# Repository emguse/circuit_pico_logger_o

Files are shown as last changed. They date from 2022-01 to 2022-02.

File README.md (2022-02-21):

# pico_logger_o

A device to record the rate of change of differential pressure using an OMRON D6F sensor, built with Raspberry Pi pico and CircuitPython.

A personal project of `emguse`, a port of the [emguse/diff_press_logger_o](https://github.com/emguse/diff_press_logger_o) project to a microcontroller.

# Notes.
- The PB-0009-A PCB board has three different power input methods, but there is no diode protection between each of them.
- Always use only one type of power input.
- If you are using the Pico's USB to supply power, it will not be able to provide power for the printer. Do not connect the printer or turn off the setting to use it.

# Features
- Time recording by RTC
- Event recording (CSV file)
- Event recording (print to thermal printer)
- Pre- and post-event recording is possible. (Number of seconds can be set.)
- Trigger detection using differences from past measurements
- Threshold change button
- Reset button

# What you need

## What to buy
- Rapberry Pi pico RP2040
- OMRON D6F-PH0505 Differential pressure sensor
- special harness with GHR-04V-S used for D6F-PH0505
- Adafruit DS3231 Precision RTC-STEMMA QT(Product ID: 5188)
- STEMMA QT / Qwiic JST SH 4-pin Cable - 100mm Long(Product ID: 4210)
- Adafruit Micro SD SPI or SDIO Card Breakout Board(Product ID: 4682)
- Thermal printer DP-EH600
- 5V 2A power supply (2.1mm DC barrel plug)

## Printed circuit board
- PB-0009-A PCB board
- 2.1mm DC barrel jack
- B2B-XH-AM(LF)(SN) JST
- B3B-XH-AM(LF)(SN) JST
- B8B-XH-AM(LF)(SN) JST
- 2.2k Ohm Resistor_SMD:R_0603_1608Metric
- 3.3k Ohm Resistor_SMD:R_0603_1608Metric
- 10k Ohm Resistor_SMD:R_0603_1608Metric
- PinHeader_1x02_P2.54mm_Vertical
- SW_Push_1P1T_NO_6x6mm
- Buzzer_12x9.5RM7.6(self-excited)
- 2SC2712 Toshiba
- BM04B-SRSS-TB_1x04-1MP_P1.00mm_Vertical JST SH

## airtight container
- enclosure_body.stl
- enclosure_lid.stl
- enclosure_sensor_fixture.stl
- Bit Insert M3x4.5xL10.0
- M3x16mm cap screws
- O-ring d84.4mm-D90.6mm-W3.1mm(G-85)
- Cable gland M10x13mm d6mm (ex. RM10L-6B takachi)
- 6mmx4mm Tube

# Usage

1. Connect Pico to your PC in Boot mode and transfer the latest `.UF2` file for Pico.
1. Transfer the modules listed in `Requirement` from the Circuitpython bundle to the `lib` folder.
1. Rename the `pico_diff_p_o.py` file to `code.py` after transferring the files in this repository.

# Requirement
- adafruit_bus_device.i2c_device
- adafruit_register
- adafruit_thermal_printer
- adafruit_ds3231

# Author

- Author: emguse

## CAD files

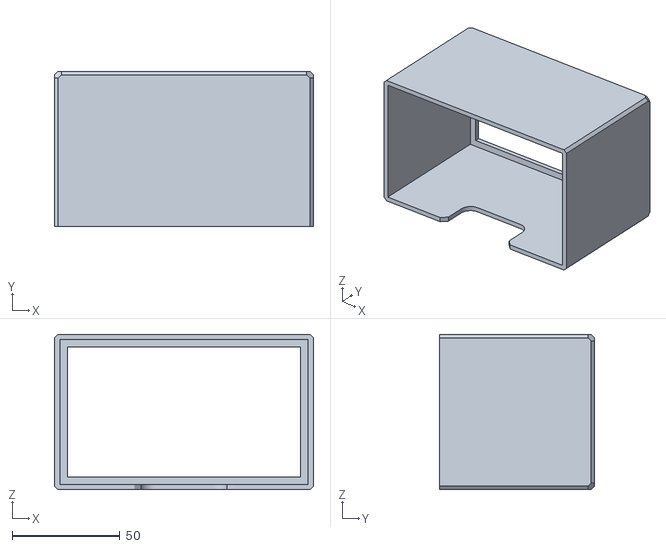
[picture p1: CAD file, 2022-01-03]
DP-EH600_Housing v1.stl
120.0 x 72.0 x 72.0

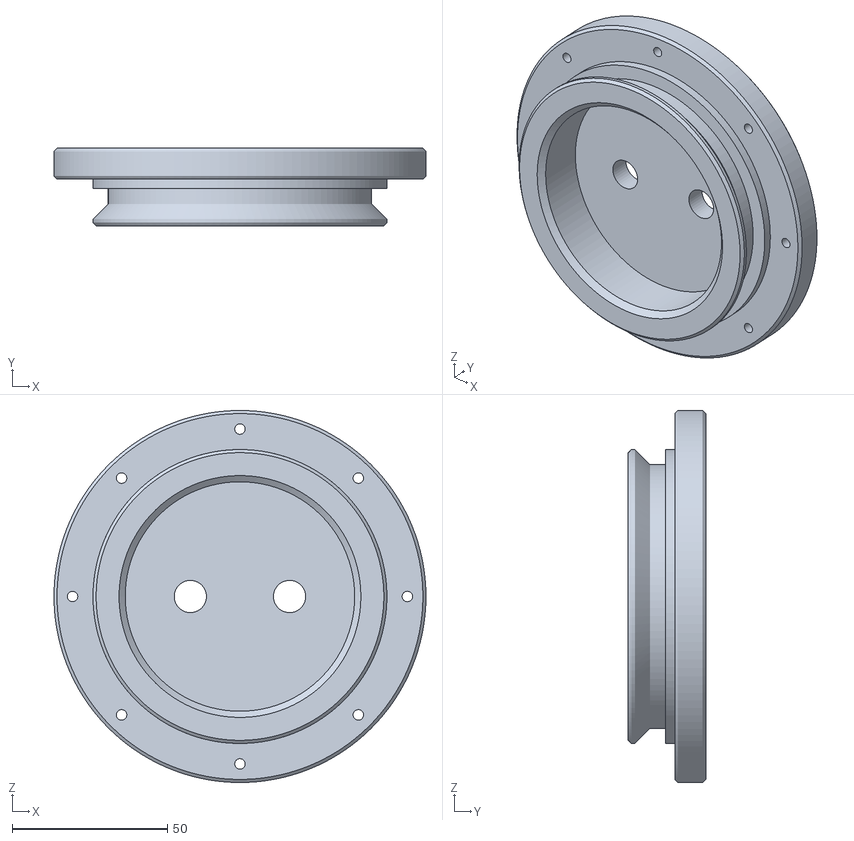
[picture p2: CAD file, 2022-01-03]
enclosure_lid.stl
120.0 x 25.0 x 120.0

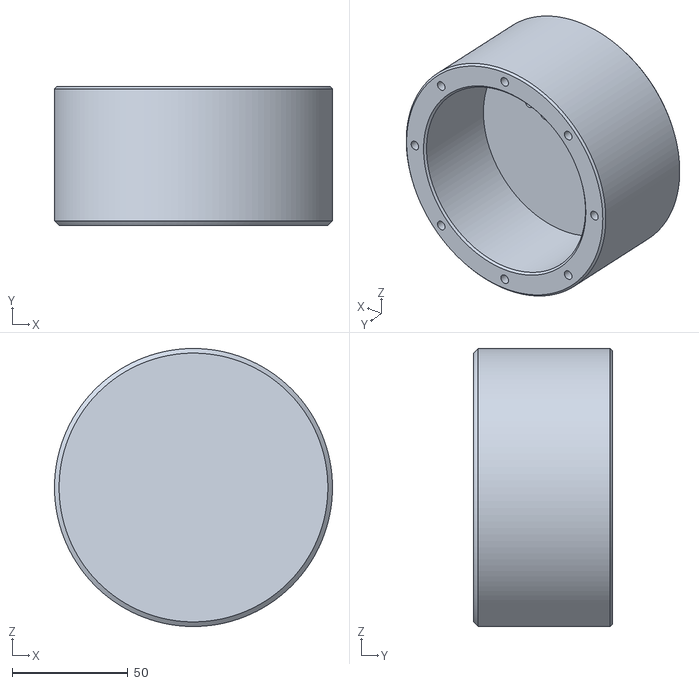
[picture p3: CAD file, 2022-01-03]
enclosure_body.stl
120.0 x 60.0 x 120.0

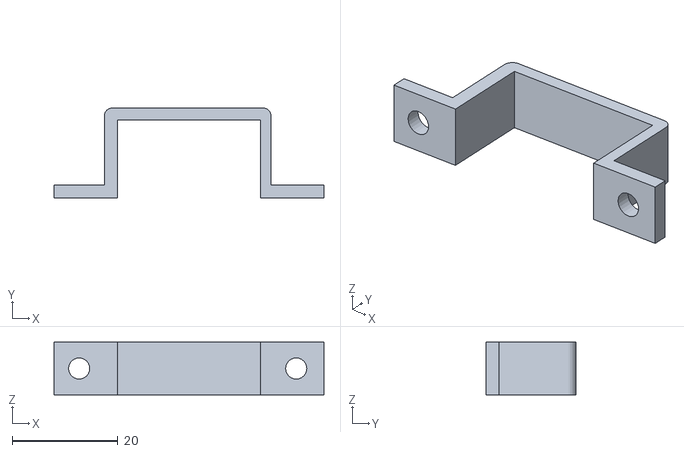
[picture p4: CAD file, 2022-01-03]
enclosure_sensor_fixture.stl
51.0 x 17.0 x 10.0

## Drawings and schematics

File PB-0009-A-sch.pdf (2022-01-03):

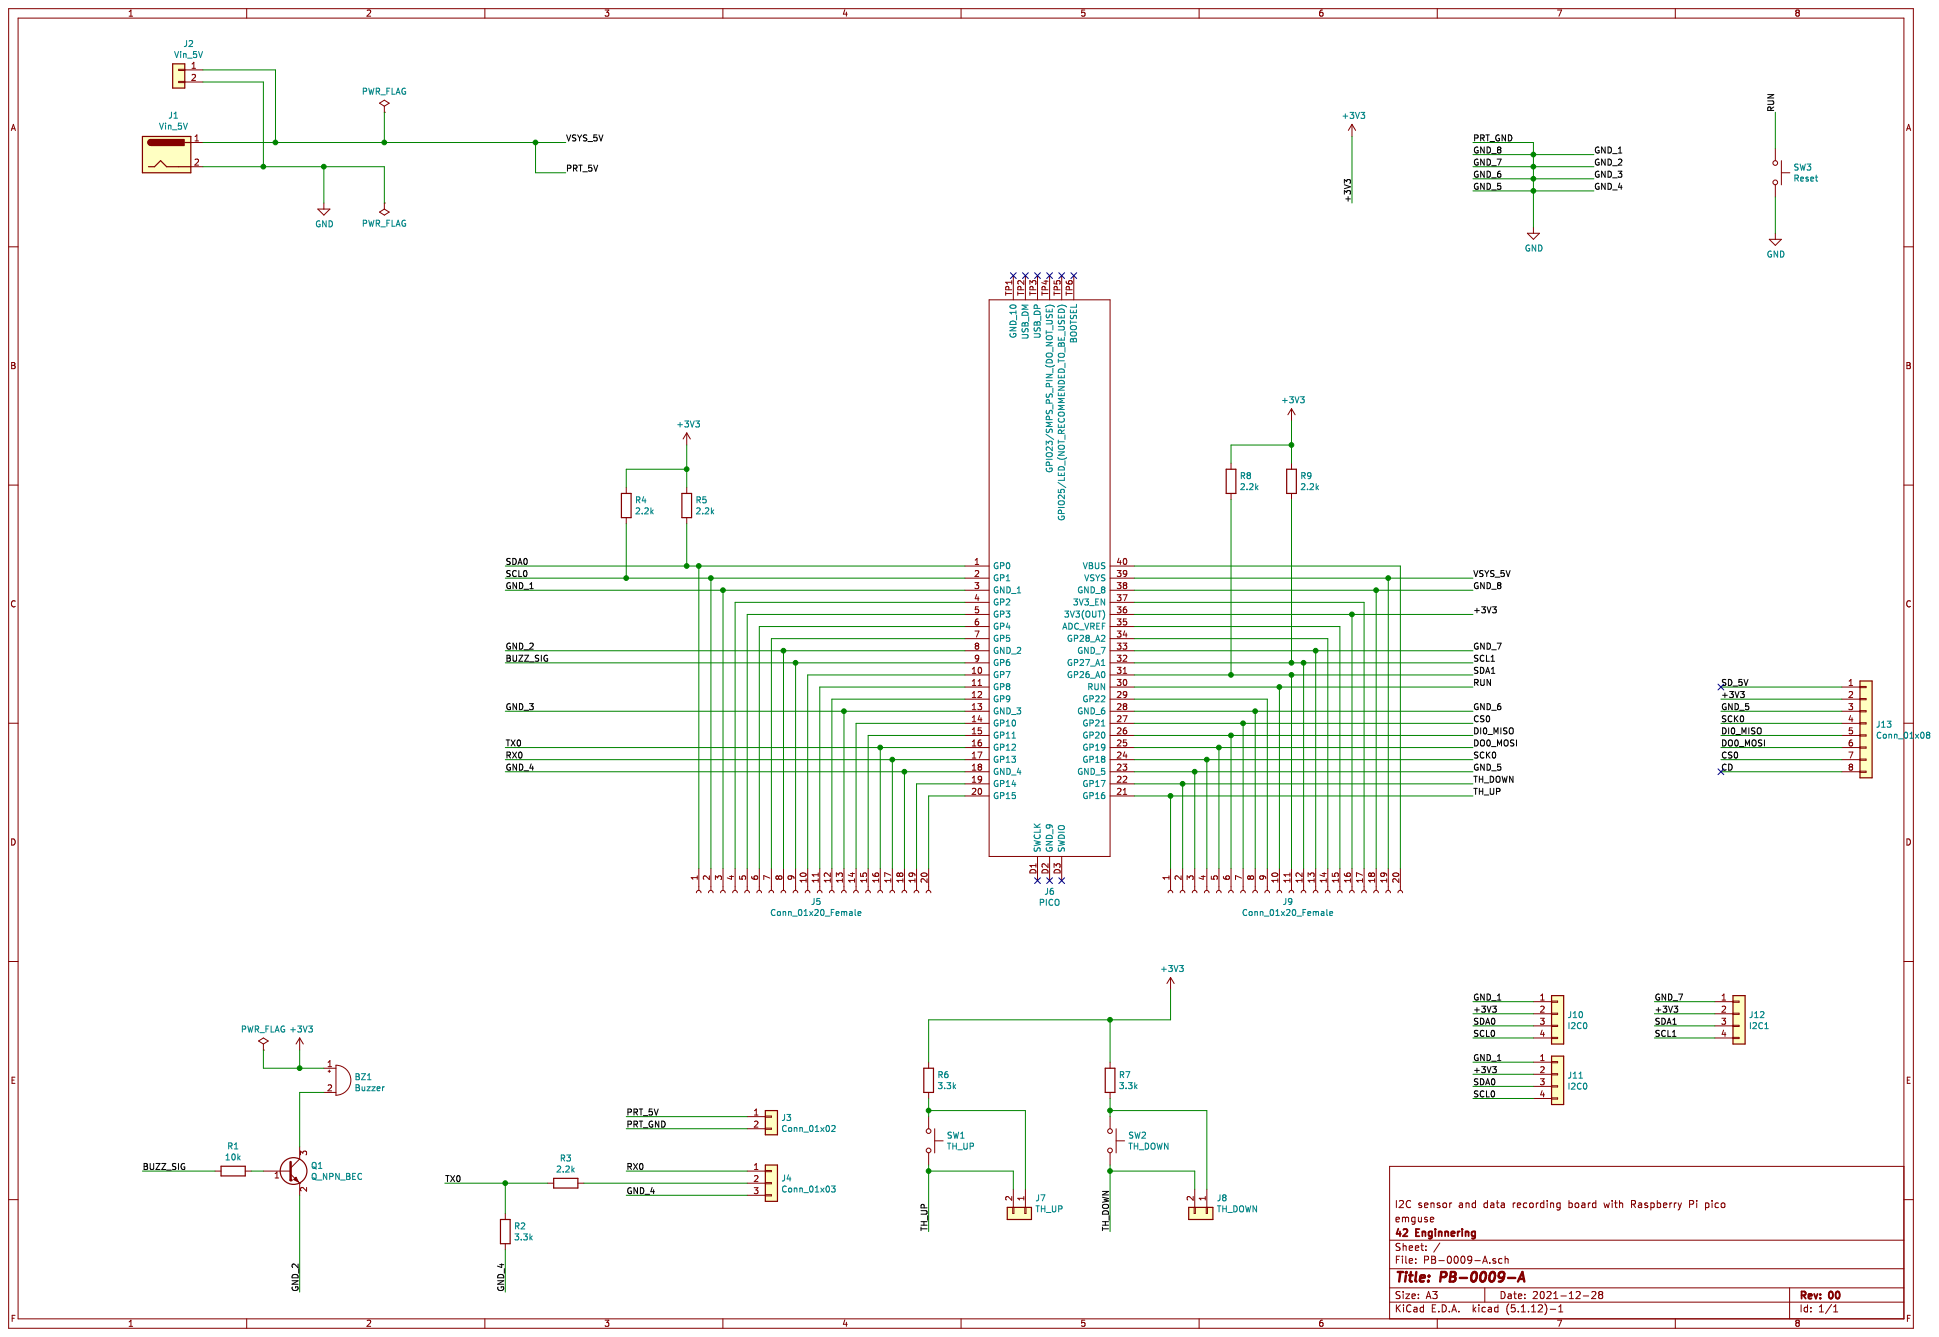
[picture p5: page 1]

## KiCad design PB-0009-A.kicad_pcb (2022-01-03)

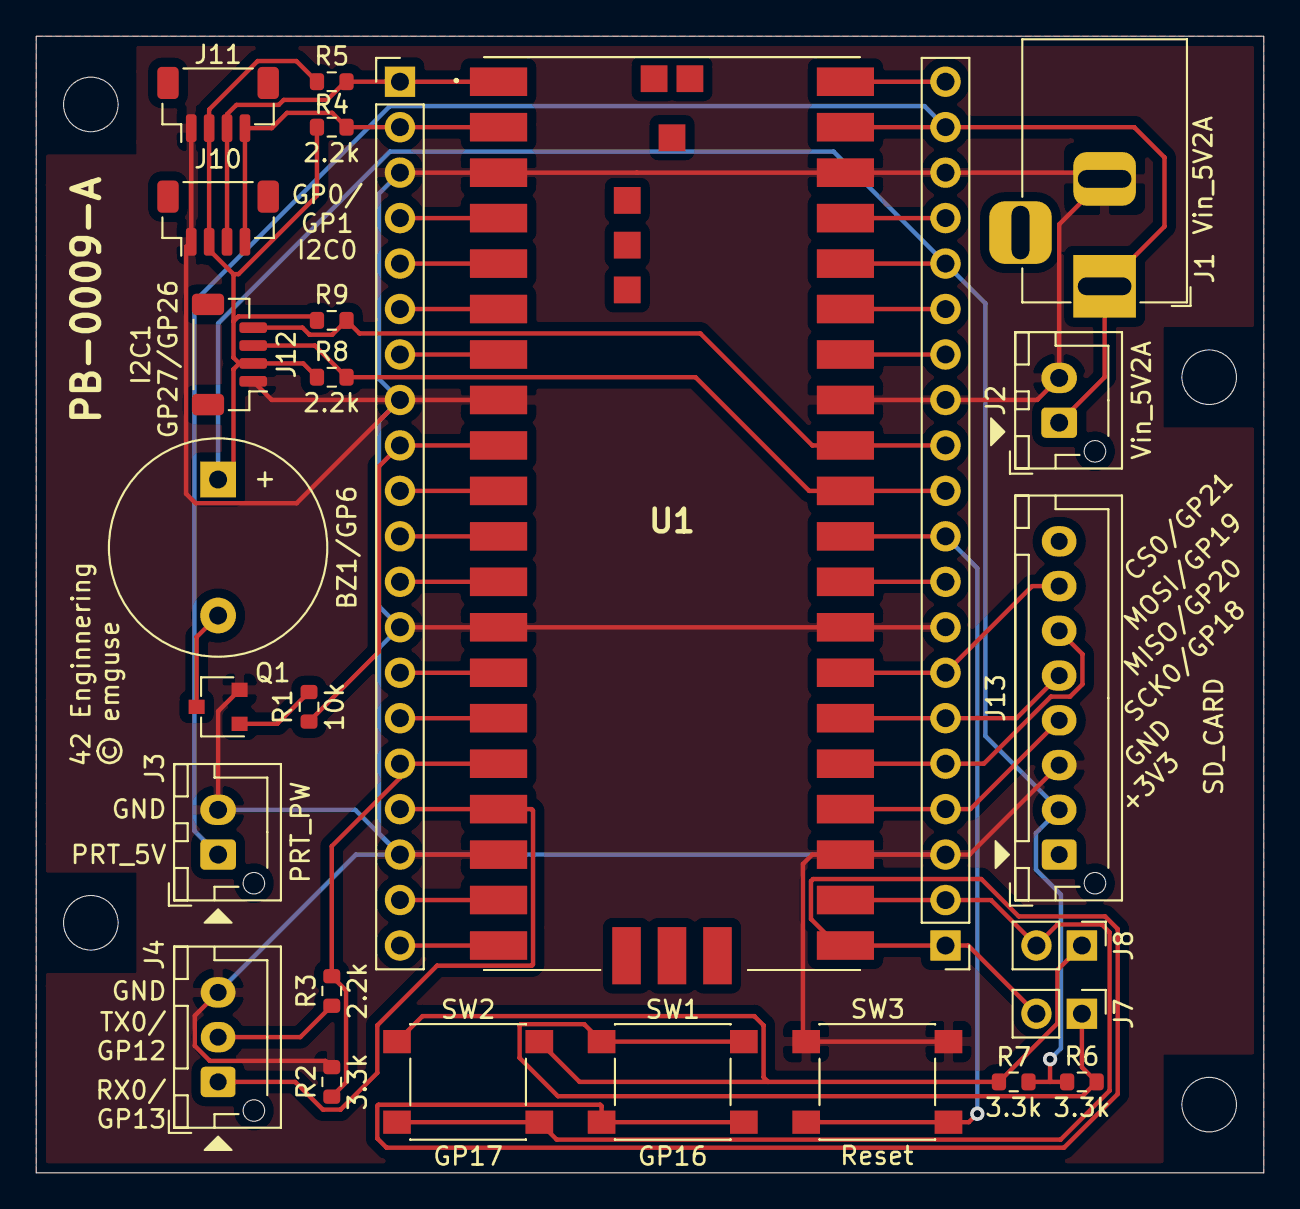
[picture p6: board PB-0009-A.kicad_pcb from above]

Board: 2 copper layers, 68.6 x 63.5 mm, 27 parts (0 on the bottom side), 38 nets.

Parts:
BZ1/GP6: Buzzer; Buzzer_12x9.5RM7.6
J1: Vin_5V2A; BarrelJack_Horizontal
J2: Vin_5V2A; JST_XH_B2B-XH-AM_1x02_P2.50mm_Vertical
J3: PRT_PW; JST_XH_B2B-XH-AM_1x02_P2.50mm_Vertical
J4: Conn_01x03; JST_XH_B3B-XH-AM_1x03_P2.50mm_Vertical
J5, J9: Conn_01x20_Female; PinHeader_1x20_P2.54mm_Vertical
J7: TH_UP; PinHeader_1x02_P2.54mm_Vertical
J8: TH_DOWN; PinHeader_1x02_P2.54mm_Vertical
J10, J11: I2C0; JST_SH_BM04B-SRSS-TB_1x04-1MP_P1.00mm_Vertical
J12: I2C1; JST_SH_BM04B-SRSS-TB_1x04-1MP_P1.00mm_Vertical
J13: SD_CARD; JST_XH_B8B-XH-AM_1x08_P2.50mm_Vertical
Q1: Q_NPN_BEC; SC-59
R1: 10k; R_0603_1608Metric
R2, R6, R7: 3.3k; R_0603_1608Metric
R3, R4, R5, R8, R9: 2.2k; R_0603_1608Metric
SW1: GP16; SW_Push_1P1T_NO_6x6mm_H9.5mm
SW2: GP17; SW_Push_1P1T_NO_6x6mm_H9.5mm
SW3: Reset; SW_Push_1P1T_NO_6x6mm_H9.5mm
U1: PICO

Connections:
+3V3: BZ1/GP6.1, J9.16, J10.2, J11.2, J12.2, J13.2, R4.1, R5.1, R6.1, R7.1, R8.1, R9.1, U1.36
/BUZZ_SIG: J5.9, R1.2, U1.9
/CS0: J9.7, J13.7, U1.27
/DI0_MISO: J9.6, J13.5, U1.26
/DO0_MOSI: J9.5, J13.6, U1.25
/PRT_5V: J1.1, J2.1, J3.1, J9.19, U1.39
/RUN: J9.10, SW3.1, U1.30
/RX0: J4.1, J5.17, U1.17
/SCK0: J9.4, J13.4, U1.24
/SCL0: J5.2, J10.4, J11.4, R4.2, U1.2
/SCL1: J9.12, J12.4, R9.2, U1.32
/SDA0: J5.1, J10.3, J11.3, R5.2, U1.1
/SDA1: J9.11, J12.3, R8.2, U1.31
/TH_DOWN: J8.2, J9.2, SW2.2, U1.22
/TH_UP: J7.2, J9.1, SW1.2, U1.21
/TX0: J5.16, R2.1, R3.2, U1.16
GND: J1.2, J2.2, J3.2, J4.3, J5.3, J5.8, J5.13, J5.18, J9.3, J9.8, J9.13, J9.18, J10.1, J11.1, J12.1, J13.3, Q1.2, R2.2, SW3.2, U1.3, U1.8, U1.13, U1.18, U1.23, U1.28, U1.33, U1.38
unnamed: BZ1/GP6.2, Q1.3
unnamed: J4.2, R3.1
unnamed: J5.4, U1.4
unnamed: J5.5, U1.5
unnamed: J5.6, U1.6
unnamed: J5.7, U1.7
unnamed: J5.10, U1.10
unnamed: J5.11, U1.11
unnamed: J5.12, U1.12
unnamed: J5.14, U1.14
unnamed: J5.15, U1.15
unnamed: J5.19, U1.19
unnamed: J5.20, U1.20
unnamed: J9.9, U1.29
unnamed: J9.14, U1.34
unnamed: J9.15, U1.35
unnamed: J9.17, U1.37
unnamed: J9.20, U1.40
unnamed: J7.1, R6.2, SW1.1
unnamed: J8.1, R7.2, SW2.1
unnamed: Q1.1, R1.1

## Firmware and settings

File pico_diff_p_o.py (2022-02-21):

import board
import digitalio
from D6F_PH0505 import DifferentialPressureSensorD6F_PH0505 as D6F_PH0505
from move_ave import MovingAverage
from ring_buffer import RingBuffer
import time
import busio
import adafruit_thermal_printer
from rtc_ds3231 import RtcDs3231
import sdcardio
import storage
from adafruit_ht16k33.segments import Seg7x4

'''
- 2022/02/14 ver.1.11
- Author : emguse
- License: MIT License
'''

CYCLE_TIME = 0.033  # sec
IVENT_LENGTH = 10  # sec
QUE_SIZE = int(IVENT_LENGTH / 2 * 1 / CYCLE_TIME)
MOVE_AVE_LENGTH = 2
REFARENCE_PAST_SAMPLE = 2
THRESHOLD = 1.0
ZERO_OFFSET = 0.0  # Zero point correction
USE_PRINTER = True
EXPORT_CSV = True
USE_BUZZER = True
I2C_SCL = board.GP1
I2C_SDA = board.GP0
PRINTER_RX = board.GP13
PRINTER_TX = board.GP12
BUTTON_A = board.GP16
BUTTON_B = board.GP17
SPI_SCK = board.GP18
SPI_MOSI = board.GP19
SPI_MISO = board.GP20
SPI_CS = board.GP21
TIME_ADJUSTING = False
TIME_TO_SET = (2021, 12, 13, 20, 45, 00, 0, -1, -1)
# TIME_TO_SET = (year, mon, date, hour, min, sec, wday, yday, isdst)
# Year, month, day, hour, minute, second, and weekday are required.
# The day of the week is not specified since it is not used. Depending on your region, you might want to use 0 to 6 and set Sunday to 0.
# Substitute "-1" for "yearday, isdst".
SD_DIR = "/sd"

class DifferentialPressureLogger:
    def __init__(self) -> None:
        i2c = busio.I2C(scl=I2C_SCL, sda=I2C_SDA)
        self.rb_p = RingBuffer(QUE_SIZE)
        self.rb_ref = RingBuffer(REFARENCE_PAST_SAMPLE)
        self.d6f_ph0505 = D6F_PH0505(i2c)
        self.rtc = RtcDs3231(i2c)
        self.thermal_printer = PrinterDpEh600()
        self.ma_p = float()
        self.past_sample = float()
        self.button_up = digitalio.DigitalInOut(BUTTON_A)
        self.button_up.switch_to_input(pull=digitalio.Pull.DOWN)
        self.button_down = digitalio.DigitalInOut(BUTTON_B)
        self.button_down.switch_to_input(pull=digitalio.Pull.DOWN)
        self.threshold = THRESHOLD
        self.buzzer = PiPi()
        self.datetime = None
    def read_dp(self):
        self.d6f_ph0505.start_order()
        self.d6f_ph0505.read_order()
        return self.d6f_ph0505.diff_p
    def read_and_record(self):
        self.ma_p = self.read_dp() - ZERO_OFFSET
        self.rb_p.append(self.ma_p)
        self.rb_ref.append(self.ma_p)
    def single_read(self):
        self.ma_p = self.read_dp() - ZERO_OFFSET
    def time_adjusting(self) -> None:
        self.rtc.time_adjusting = True
        self.rtc.time_to_set = TIME_TO_SET
        self.rtc.adjust()
        t = self.rtc.read()
        print(t)
        self.rtc.time_adjusting = False
    def timestamp(self) -> None:
        self.datetime = self.rtc.read()
        print(
            "{:04}{:02}{:02}T{:02}{:02}{:02}".format(
                self.datetime.tm_year, self.datetime.tm_mon, self.datetime.tm_mday,
                self.datetime.tm_hour, self.datetime.tm_min, self.datetime.tm_sec
            )
        )
    def pprint_timestamp(self) -> None:
        if USE_PRINTER:
            self.thermal_printer.printer.print(
                "{:04}{:02}{:02}T{:02}{:02}{:02}".format(
                    self.datetime.tm_year, self.datetime.tm_mon, self.datetime.tm_mday, 
                    self.datetime.tm_hour, self.datetime.tm_min, self.datetime.tm_sec
                )
            )

    def threshold_up(self) -> None:
        print("up")
        self.threshold = round(self.threshold + 0.1, 3)
        if USE_PRINTER:
            self.thermal_printer.printer.print("THRESHOLD:" + str(self.threshold))
        time.sleep(0.5)
    def threshold_down(self) -> None:
        print("down")
        self.threshold = round(self.threshold - 0.1, 3)
        if USE_PRINTER:
            self.thermal_printer.printer.print("THRESHOLD:" + str(self.threshold))
        time.sleep(0.5)
    def export_csv(self, d_a) -> None:
        tstamp = str(
            "{:04}{:02}{:02}T{:02}{:02}{:02}".format(
                self.datetime.tm_year, self.datetime.tm_mon, self.datetime.tm_mday,
                self.datetime.tm_hour, self.datetime.tm_min, self.datetime.tm_sec
            ))
        filename = str(SD_DIR + '/' + tstamp + '.csv')
        try:
            with open(filename, 'w') as f:
                print("Start exporting data")
                for i in d_a:
                    f.write(str(i)+'\n')
                print("Export Complete")
        except:
            print("File export error")

class PiPi:
    def __init__(self) -> None:
        self.buzzer = digitalio.DigitalInOut(board.GP6)
        self.buzzer.direction = digitalio.Direction.OUTPUT
    def pi(self) -> None:
        self.buzzer.value = True
        time.sleep(0.03)
        self.buzzer.value = False

class PrinterDpEh600:
    def __init__(self) -> None:
        self.TX = PRINTER_TX
        self.RX = PRINTER_RX
        self.Thermal_Printer = adafruit_thermal_printer.get_printer_class(2.69)
        self.uart = busio.UART(self.TX, self.RX, baudrate=115200)
        self.printer = self.Thermal_Printer(self.uart, auto_warm_up=False)
    def print(self, data) -> None:
        self.printer.print(data)
    def feed(self, lines) -> None:
        self.printer.feed(lines)

def main():
    logger = DifferentialPressureLogger()
    ma = MovingAverage(MOVE_AVE_LENGTH, True)
    past_time = 0
    past_disp_time = 0

    led = digitalio.DigitalInOut(board.LED)
    led.direction = digitalio.Direction.OUTPUT

    i2c1 = busio.I2C(board.GP27, board.GP26)
    display = Seg7x4(i2c1)
    display.brightness = 0.5

    if EXPORT_CSV:
        spi = busio.SPI(SPI_SCK, MOSI=SPI_MOSI, MISO=SPI_MISO)
        cs = SPI_CS
        sdcard = sdcardio.SDCard(spi, cs)
        vfs = storage.VfsFat(sdcard)
        storage.mount(vfs, SD_DIR)

    if TIME_ADJUSTING == True:
        logger.time_adjusting()
    logger.timestamp()
    logger.pprint_timestamp()
    if USE_PRINTER:
        logger.thermal_printer.printer.print("THRESHOLD:" + str(logger.threshold))

    for _ in range(QUE_SIZE): # buffer filling
        logger.read_and_record()
    logger.past_sample = logger.ma_p

    while True:
        logger.read_and_record()
        delta = logger.past_sample - logger.ma_p
        if past_time <= time.time():
            if abs(delta) >= logger.threshold:
                triggered_p = logger.ma_p
                # print("diff_p:" + str(round(ma_p, 4)) + "  Δ:" + str(round(delta, 4)) + "  time:" + str(time.time()))
                past_time = time.time() + IVENT_LENGTH
                # File output processing
                if EXPORT_CSV == True:
                    after_p = []
                    for _ in range(QUE_SIZE):
                        logger.single_read()
                        after_p.append(logger.ma_p)
                    Forward_p = []
                    for i in range(QUE_SIZE):
                        Forward_p.append(logger.rb_p.popleft())
                    Forward_p.extend(after_p)
                    logger.export_csv(Forward_p)
                logger.timestamp()
                print((round(triggered_p, 4), round(delta, 4)))
                logger.pprint_timestamp()
                if USE_PRINTER:
                    logger.thermal_printer.printer.print(
                        str(
                            "diff_P:"
                            + str(round(triggered_p, 4))
                            + ", delta:"
                            + str(round(delta, 4))
                        )
                    )
                    logger.thermal_printer.printer.feed(1)
                if USE_BUZZER:
                    logger.buzzer.pi()
                for _ in range(QUE_SIZE): # buffer filling
                    logger.read_and_record()
        logger.past_sample = logger.ma_p

        if logger.button_up.value:
            logger.threshold_up()
        if logger.button_down.value:
            logger.threshold_down()

        t = logger.rtc.read()
        if t.tm_sec % 2 == 0:
            led.value = True
        else:
            led.value = False
        
        if past_disp_time <= time.time():
            display.fill(0)
            display.print('{:.2f}'.format(logger.ma_p))
            past_disp_time = time.time() + 0.2

if __name__ == "__main__":
    main()

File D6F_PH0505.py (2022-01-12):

import board
import busio
import time
from adafruit_bus_device.i2c_device import I2CDevice

'''
- 2021/12/14 ver.1.00
- Author : emguse
- License: MIT License
'''

RANGE_100 = 100  # ±50Pa(D6F-PH0505)
RANGE_1000 = 1000  # ±500Pa(D6F-PH5050)
RANGE_250 = 250  # 0-250Pa(D6F-PH0025)

I2C_ADDRES = 0x6C  # i2c addres
CRC_ENABLE = False

class DifferentialPressureSensorD6F_PH0505():
    def __init__(self, i2c: I2C) -> None:
        self.d6f_addres = I2C_ADDRES
        self.crc_enable = CRC_ENABLE
        self.device = I2CDevice(i2c, self.d6f_addres)
        self.diff_p = 0
        with self.device:
            init_order = bytes([0x0B, 0x00])
            time.sleep(0.0002)
            self.device.write(init_order)
        if self.crc_enable == True:
            with self.device:
                crc_enable_order = bytes([0xD0, 0x49, 0x18, 0x02])
                self.device.write(crc_enable_order)
    def CRC(d):
        crc = 0x00
        for s in d:
            crc ^= s
            for _ in range(8):
                if crc & 0x80:
                    crc <<= 1
                    crc ^= 0x131
                else:
                    crc <<= 1
        return crc
    def start_order(self) -> None:
        with self.device:
            start_order = bytes([0x00, 0xD0, 0x40, 0x18, 0x06])
            self.device.write(start_order)
            time.sleep(0.033)
    def read_order(self) -> None:
        with self.device:
            read_order = bytes([0x00, 0xD0, 0x51, 0x2C])
            self.device.write(read_order)
            read_addres = bytes([0x07])
            if self.crc_enable == True:
                raw = bytearray(3)
                self.device.write_then_readinto(read_addres, raw)
                pv = raw[0] << 8 | raw[1]
                self.diff_p = (pv - 1024) / 60000 * RANGE_100 - RANGE_100 / 2
                if raw[2] != self.CRC(raw[:2]):
                    raise RuntimeError("CRC Error!!")
            else:
                raw = bytearray(2)
                self.device.write_then_readinto(read_addres, raw)
                pv = raw[0] << 8 | raw[1]
                self.diff_p = (pv - 1024) / 60000 * RANGE_100 - RANGE_100 / 2
    def hw_reset(self):
        with self.device:
            reset_order = bytes([0x00, 0x80])
            self.device.write(reset_order)

def main(): 
    I2C_SCL = board.GP1
    I2C_SDA = board.GP0  
    i2c = busio.I2C(scl=I2C_SCL, sda=I2C_SDA)
    d6f_ph0505 = DifferentialPressureSensorD6F_PH0505(i2c)
    while True:
        d6f_ph0505.start_order()
        d6f_ph0505.read_order()
        print("diff_p:" + str(round(d6f_ph0505.diff_p, 4)))

if __name__ == "__main__":
    main()

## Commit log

2022-01-13 Added blinking onboard LED to check for life and death
2022-01-28 Improved log accuracy by rearranging the processing order. Improvement of the timestamp system. Bug fixes.
    [circuit_pico_diff_p_o.py]
2022-01-29 Separate timestamp processing into getting and printing.
2022-02-14 Fix comment-out deletion errors
    [circuit_pico_diff_p_o.py]

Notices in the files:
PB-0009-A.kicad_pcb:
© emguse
